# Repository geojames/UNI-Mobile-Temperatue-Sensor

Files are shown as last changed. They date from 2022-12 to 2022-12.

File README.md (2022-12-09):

# UNI-Mobile-Temperatue-Sensor
Open-source Mobile Air and Surface Temperature Sensor for Urban Heat Island Mapping

### Main Parts List
#### Data Logger
| Qty | Part | Link |
| --- | --- | --- |
| 1 | Adafruit QTPy RP2040 | https://www.adafruit.com/product/4900 | 	
| 1 | Adafruit Miniboost | https://www.adafruit.com/product/4654 |
| 1 | Monochrome 128x64 OLED | https://www.adafruit.com/product/938 |
| 1 | 3-AA Battery Holder | https://www.adafruit.com/product/4779 |
| 1 | SparkFun OpenLog | https://www.sparkfun.com/products/13712 |
| 6 | Stemma Cables 50mm | https://www.adafruit.com/product/4399 |
| 1 | SPDT Toggle Switch | https://www.adafruit.com/product/3221 |
| 1 | Main Circuit Board (in CircuitBoard folder) | |
#### Sensors
| Qty | Part | Link |
| --- | --- | --- |
| 1 | Adafruit Mini GPS | https://www.adafruit.com/product/4415 |
| 1 | Melexis MLX90614 | https://www.adafruit.com/product/1747 |
| 1 | Adafruit SHT40 (Temp) | https://www.adafruit.com/product/4885 |
| 1 | Adafruit BH1750 (Light) |  https://www.adafruit.com/product/4681 |
| 1 | Stemma QT JST SH Conn | https://www.adafruit.com/product/4208 |
| 1 | MLX Circuit Board (in CircuitBoard folder) | |
#### Accessories
| Qty | Part | Link |
| --- | --- | --- |
| 1 | MicroSD card (8gb)
| 1 | 36" (1m) USB Cable | https://www.adafruit.com/product/592 | 
|  | or 4con x 28AGW Cable | https://www.digikey.com/en/products/detail/cnc-tech/2725-2828-BL-01000-T/6023699 |
| 1 | JST PH 2-Pin Cable 100mm | https://www.adafruit.com/product/261 |
| 2 | JST PH 2-pin Board Conn | https://www.digikey.com/en/products/detail/jst-sales-america-inc/B2B-PH-K-S-LF-SN/926611 |
| 1 | Suction cup lifter | https://www.harborfreight.com/automotive/auto-body-trim/windows-windshields/suction-cup-lifters/4-23-in-125-lb-dual-suction-cup-lifter-57501.html |
|(optional)| | |
| 1 | JST PH 4-pin Cable  | https://www.adafruit.com/product/3955 |
| 1 | JST PH 4-pin Bard Connector | https://www.digikey.com/en/products/detail/jst-sales-america-inc/B4B-PH-K-S-LF-SN/926613 |
#### Hardware
| Qty | Part | Link |
| --- | --- | --- |
| 1 | M2.5 Standoff Kit | https://www.adafruit.com/product/3658 |
| 10 | M2.5 Heatset inserts | https://www.mcmaster.com/94459A439 |
| 10 | M3 Heatset inserts | https://www.mcmaster.com/94459A130 |
| 4 | M4 Heatset inserts | https://www.mcmaster.com/94459A160 |
| 4 | M3 x 60mm Panhead Screw | https://www.mcmaster.com/catalog/92005A140 |
| 4 | M3 x 10mm Hexdrive Screw | https://www.mcmaster.com/catalog/92095A182 |
| 4 | M4 x 12mm Button head | https://www.mcmaster.com/catalog/92137A307 |
| 2 | M4 x 30mm Hexhead Screw | https://www.mcmaster.com/catalog/91287A118 |
| 2 | M4 Wingnut | https://www.mcmaster.com/catalog/94300A310 |
| 2 | M4 Flat washer | https://www.mcmaster.com/catalog/98688A114 |
| 2 | M4 Internal-Tooth Washer | https://www.mcmaster.com/93925A419 |
| 2 | Rubber washer (~0.3" ID x 1" OD) | https://www.mcmaster.com/90133A260/ |

#### Tools 
Soldering Iron, Solder, Wire strippers, Diagonal cutters, Screw drivers, Allen keys

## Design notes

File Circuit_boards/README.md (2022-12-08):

# UNI-Mobile-Temperatue-Sensor
## Circuit Board Files

These file contain the GERBER files nessesary to order the circuit boards for this project.

The basic configuation for a 2-sided circuit board from any of the major online vendors will be fine.

I use https://jlcpcb.com/

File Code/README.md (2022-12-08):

# UNI-Mobile-Temperatue-Sensor
## Circuit Python Firmware, Code, Libraries

### Firmware
Upload the firmware *.uf2 file to QTPY RP2040
- https://learn.adafruit.com/adafruit-qt-py-2040/circuitpython

### Code and Libraries
Copy the 'lib' folder and the code.py file to the mounted CircuitPython drive

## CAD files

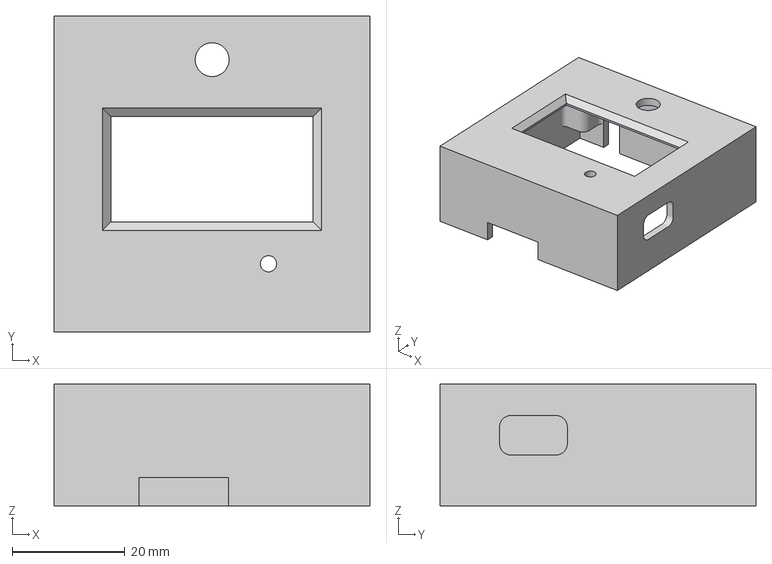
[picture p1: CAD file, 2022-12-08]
3D_Prints/data_MainBody.3mf
56.0 x 56.0 x 21.6 mm

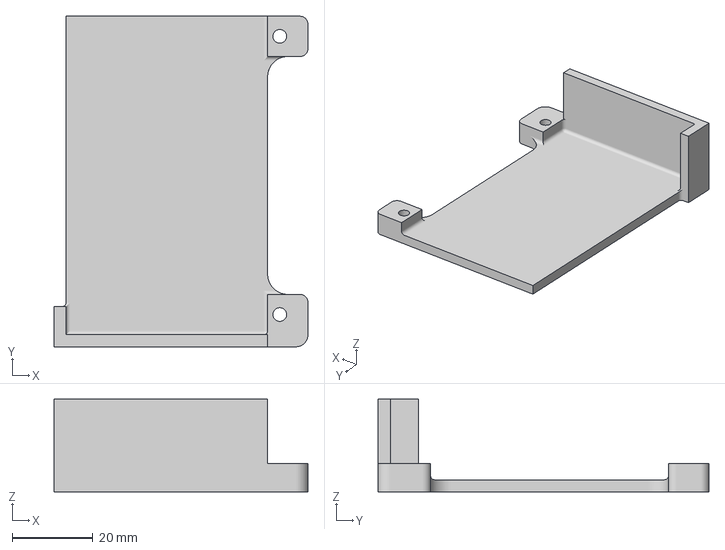
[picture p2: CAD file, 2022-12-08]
3D_Prints/data_Batt_plate.3mf
63.0 x 82.0 x 23.0 mm

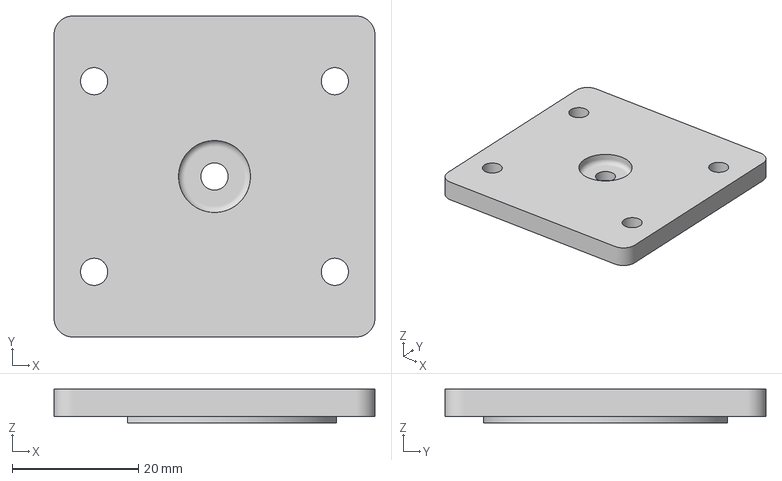
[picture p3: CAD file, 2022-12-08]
3D_Prints/elbow_plate_v3.3mf
50.8 x 50.8 x 5.38 mm

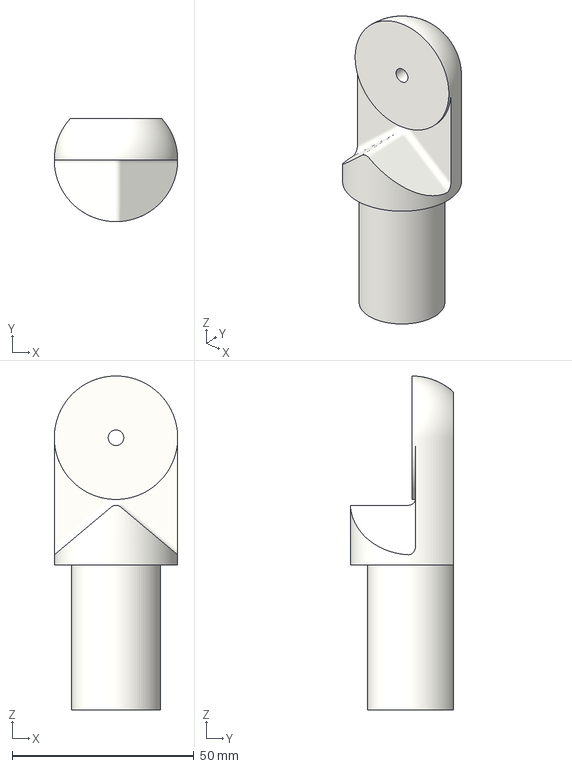
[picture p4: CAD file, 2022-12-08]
3D_Prints/elbow_bottom_v3.3mf
34.0 x 28.5 x 92.0 mm

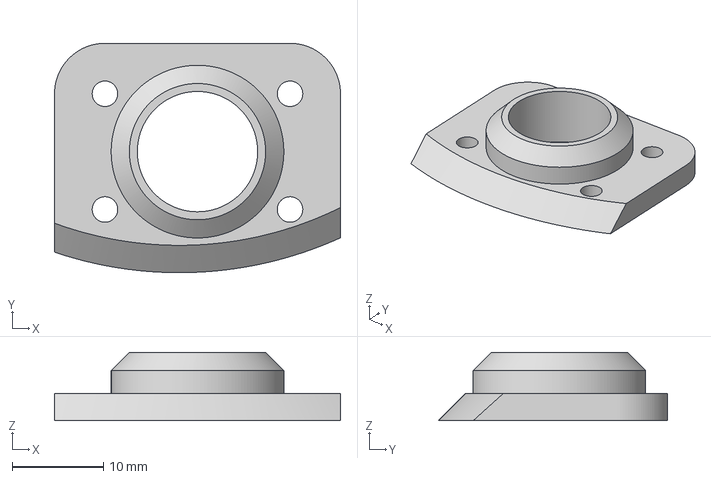
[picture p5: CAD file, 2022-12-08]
3D_Prints/Light_cap_v2.3mf
31.4 x 25.2 x 7.50 mm

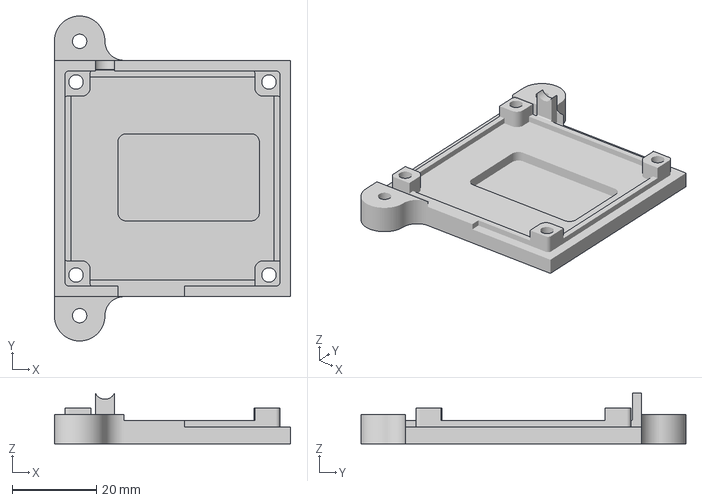
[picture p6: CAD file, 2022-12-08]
3D_Prints/data_BackLid.3mf
56.0 x 77.0 x 12.0 mm

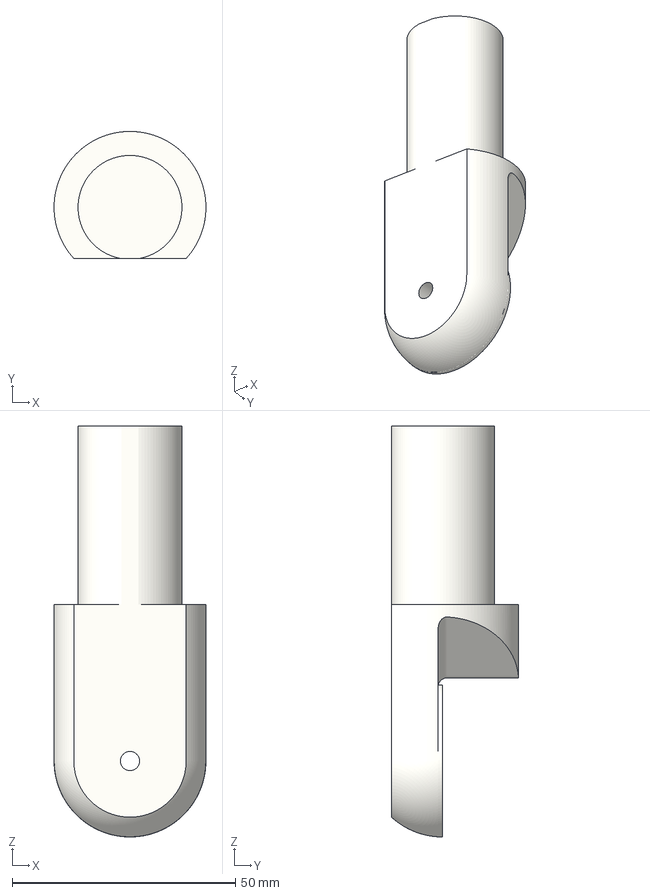
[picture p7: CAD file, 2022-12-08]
3D_Prints/elbow_middle_v3.3mf
34.0 x 28.5 x 92.0 mm

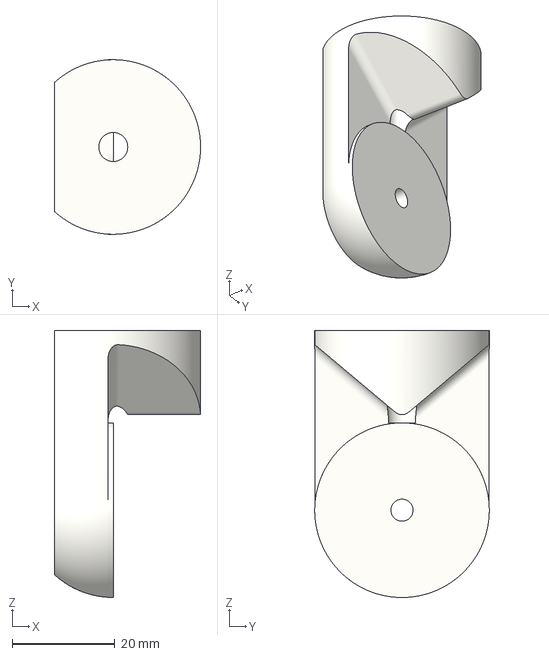
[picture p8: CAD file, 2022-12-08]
3D_Prints/elbow_top_v3.3mf
28.5 x 34.0 x 52.0 mm

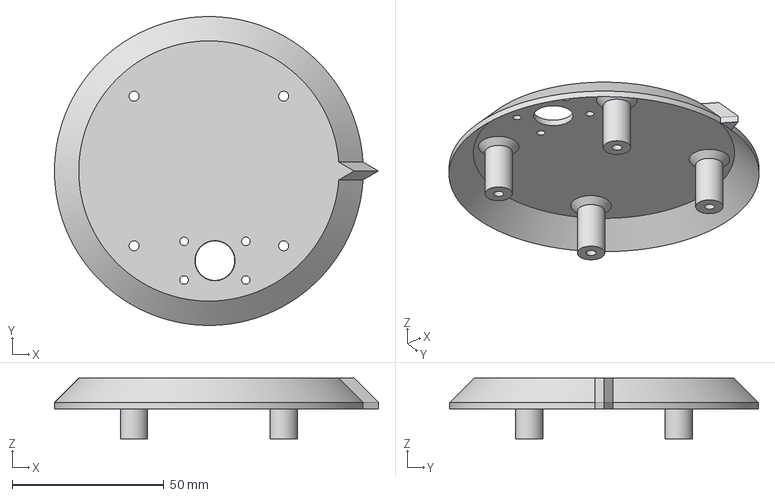
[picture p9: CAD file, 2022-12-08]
3D_Prints/Top_Light_v2.3mf
106.6 x 101.6 x 20.0 mm

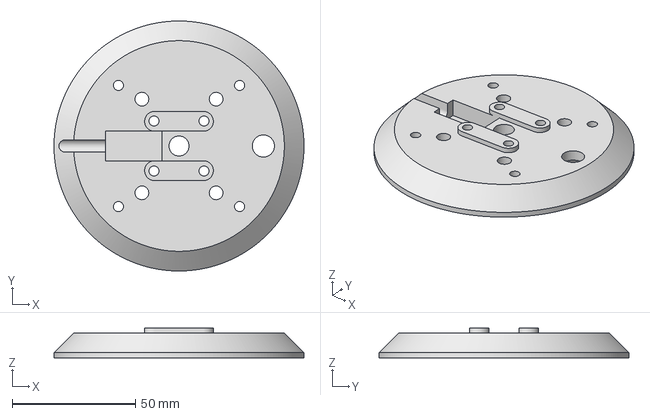
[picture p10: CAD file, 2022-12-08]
3D_Prints/Base_AMPS_v2.3mf
101.6 x 101.6 x 12.2 mm

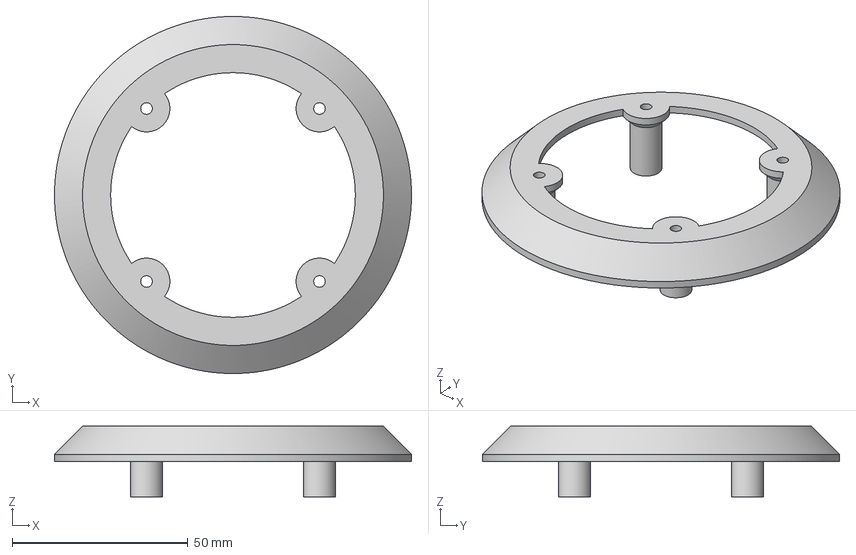
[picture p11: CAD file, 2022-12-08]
3D_Prints/Mid_Louver_v2.3mf
101.6 x 101.6 x 20.1 mm

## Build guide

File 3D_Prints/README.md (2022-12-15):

# UNI-Mobile-Temperatue-Sensor
## 3D Print Files

Print one of each file, execpt Elbow_middle - print two.

I printed in white PLA with 3 perimiters and 15% infill. Most of the models have a large flat surface from printing (most rotated to print "upsidedown"). No supports should be needed.

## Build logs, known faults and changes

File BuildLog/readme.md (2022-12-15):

# Basic build log for the sensors

### More detailed build log coming in early 2024

1. Print 3D Parts add heat set inserts per the images below
2. Order Circuit Boards - assemble per the photos below
3. Suction mount - Cut the suction mount in half across the handle, drill and add heat set inserts
4. Arm - Epoxy the arm/elbow parts into the suction mount and aluminium pipe
5. Assemble all the parts together
6. Upload the Circuit Python Firmware (Code folder) to the QTPy RP2040
7. Uploard the main logging code to the QTPy
---
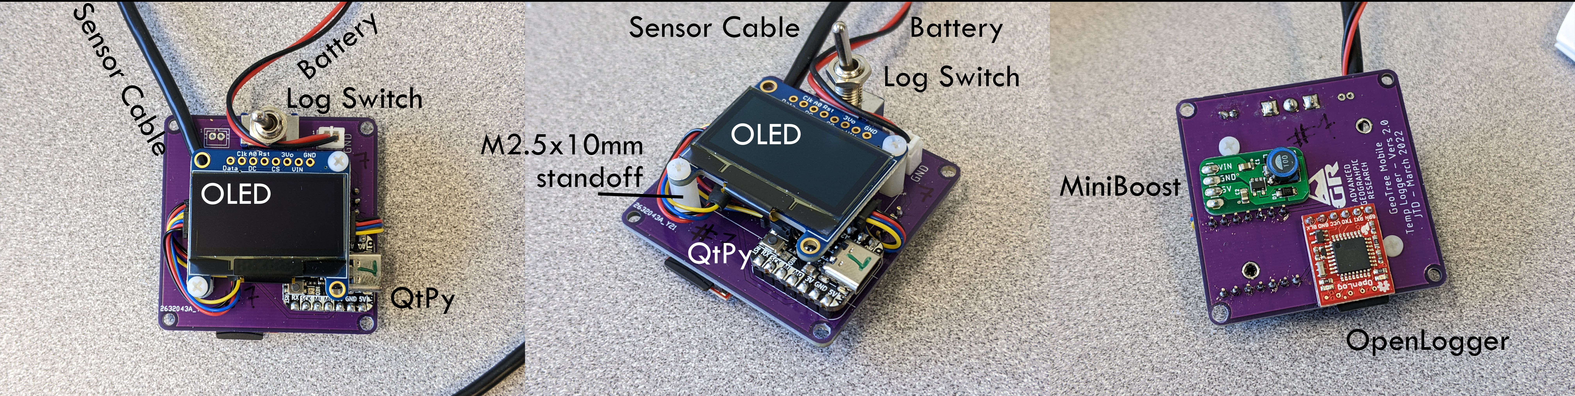
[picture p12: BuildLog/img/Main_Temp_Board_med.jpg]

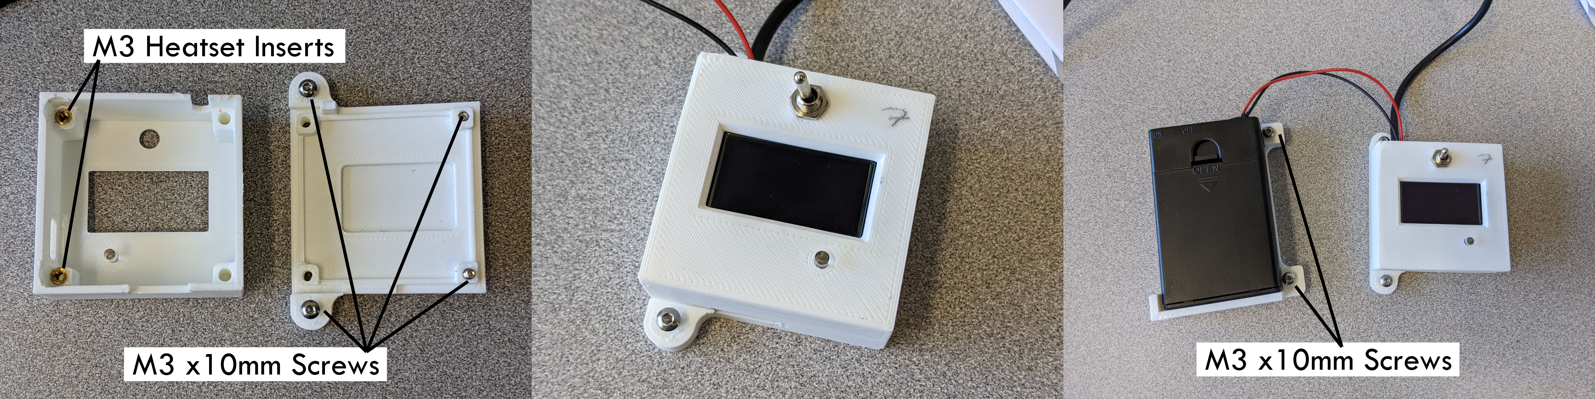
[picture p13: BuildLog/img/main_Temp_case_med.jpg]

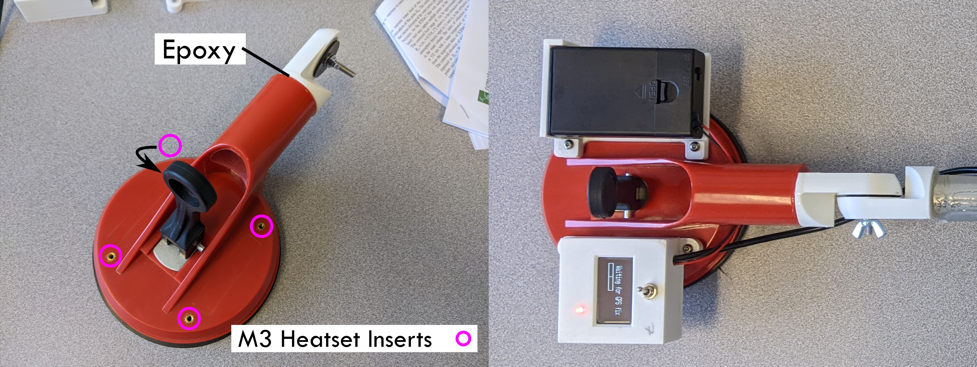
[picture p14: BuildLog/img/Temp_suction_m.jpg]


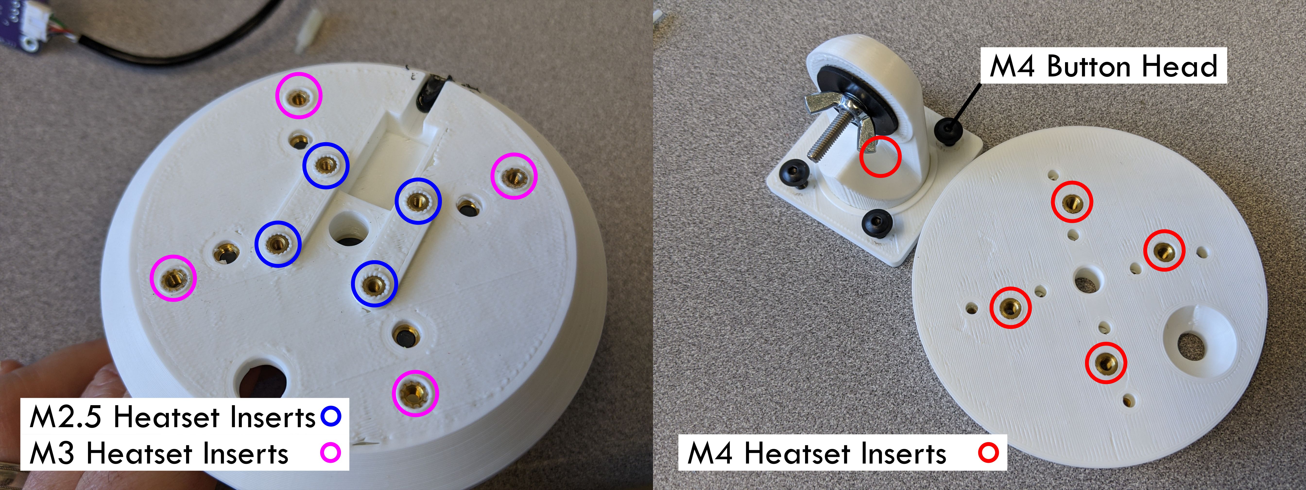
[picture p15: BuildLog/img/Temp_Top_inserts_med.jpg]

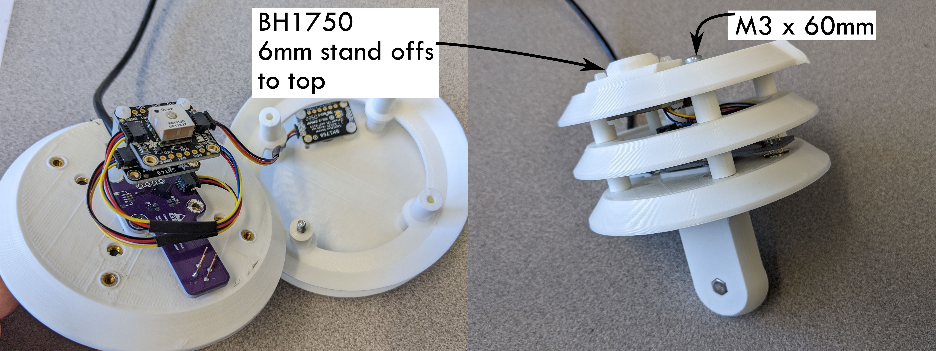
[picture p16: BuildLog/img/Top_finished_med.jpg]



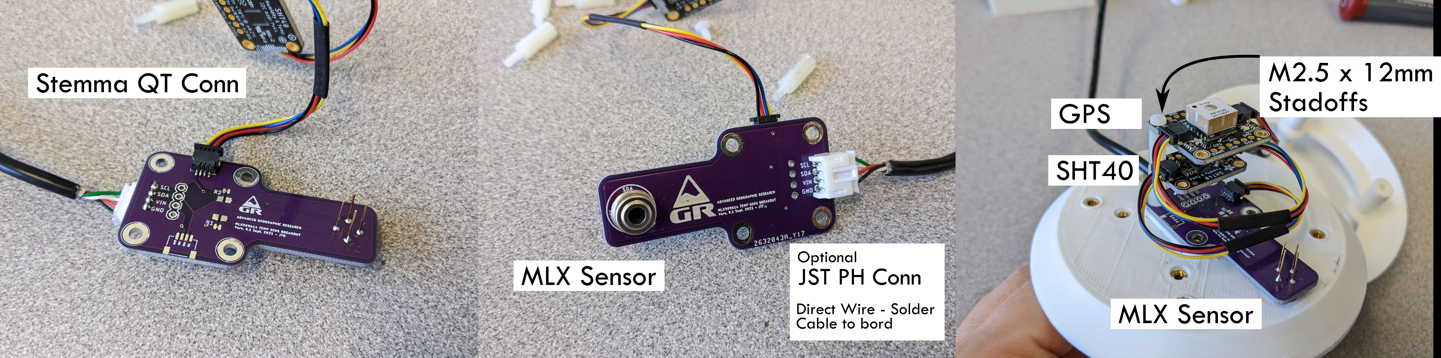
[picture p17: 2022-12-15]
BuildLog/img/Top_MLX_stack_med.jpg

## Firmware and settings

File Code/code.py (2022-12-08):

# -*- coding: utf-8 -*-
# VERSION  5.4, July 2022
# FOR Circuit Pyhton vers. 6.3 (2021-06-01)

import time
import board
import busio
import displayio
import digitalio
import adafruit_ssd1306
import adafruit_sht4x
import adafruit_mlx90614
import adafruit_bh1750
import adafruit_gps
import neopixel

run = True
i2c = busio.I2C(board.SCL1, board.SDA1)
uart = busio.UART(board.TX, board.RX, baudrate=9600)

pixel = neopixel.NeoPixel(board.NEOPIXEL, 1)
pixel.fill((255, 0, 0))
log_switch = digitalio.DigitalInOut(board.D1)
log_switch.direction = digitalio.Direction.INPUT
log_switch.pull = digitalio.Pull.DOWN
oled_reset = digitalio.DigitalInOut(board.D0)
display = adafruit_ssd1306.SSD1306_I2C(128, 32, i2c, addr=0x3D, reset=oled_reset)
display.fill(1)
display.show()
WIDTH = 128
HEIGHT = 64
text = "GEOTREE TEMP LOGGER\nVers. 0.54 + July21"
display.fill(0)
display.text(text, 7, 7, 1)
display.show()
try:
    sht = adafruit_sht4x.SHT4x(i2c)
    sht.mode = adafruit_sht4x.Mode.NOHEAT_HIGHPRECISION
except:
    text = "ERROR:\nTemp Sensor Not Found"
    display.fill(0)
    display.text(text, 7, 0, 1)
    display.show()
try:
    mlx = adafruit_mlx90614.MLX90614(i2c)
except:
    text = "ERROR:\nSurface Not Found"
    display.fill(0)
    display.text(text, 7, 0, 1)
    display.show()
try:
    lux = adafruit_bh1750.BH1750(i2c)
except:
    text = "ERROR:\nLight Not Found"
    display.fill(0)
    display.text(text, 7, 0, 1)
    display.show()
try:
    gps = adafruit_gps.GPS_GtopI2C(i2c)
    gps.send_command(b"PMTK314,0,1,0,0,0,0,0,0,0,0,0,0,0,0,0,0,0,0,0")
    gps.send_command(b"PMTK220,500")
    gps.update()
except:
    text = "ERROR:\nGPS Not Found"
    display.fill(0)
    display.text(text, 7, 0, 1)
    display.show()

last_print = time.monotonic()
while log_switch.value is True:
    text = "!!!!!!\nTurn Log Swictch\nto OFF to continue\n!!!!!!"
    display.fill(0)
    display.text(text, 7, 0, 1)
    display.show()
    pixel.fill((255, 0, 0))
    time.sleep(0.5)
fix_count = 0
while gps.has_fix is False:
    text = "Waiting for GPS fix"
    gps.update()
    current = time.monotonic()
    if current - last_print >= 1:
        last_print = current
        if fix_count == 0:
            display.fill(0)
            display.text(text, 7, 8, 1)
            display.rect(0, 18, int(WIDTH * 0.25), 6, 1)
            display.show()
            pixel.fill((255, 0, 0))
        elif fix_count == 1:
            display.rect(0, 18, int(WIDTH * 0.5), 6, 1)
            display.show()
            pixel.fill((50, 0, 0))
        elif fix_count == 3:
            display.rect(0, 18, int(WIDTH * 0.75), 6, 1)
            display.show()
            pixel.fill((255, 0, 0))
        elif fix_count == 4:
            display.rect(0, 18, int(WIDTH), 6, 1)
            display.show()
            pixel.fill((50, 0, 0))
        fix_count += 1
        if fix_count >= 5:
            fix_count = 0
file_num = 1
ready_sw = 0
print("GPS WAITING: %i" % gps.in_waiting)

while gps.in_waiting > 24:
    data = gps.read(200)
    print("flush...")
while run == True:
    if log_switch.value is False:
        if ready_sw == 0:
            gps.update()
            log_state = 0
            pixel.fill((0, 255, 0))
            display.fill(0)
            text = "GPS READY...\n  Toggle Switch\n  to Start Logging"
            display.text(text, 7, 2, 1)
            display.show()
            time.sleep(1.0)
            ready_sw = 1
    elif log_switch.value is True:
        gps.update()
        current = time.monotonic()
        # print("*** Time *** %0.3f"%(current - last_print))
        if log_state == 0:
            log_state = 1
            ready_sw = 0
            ready_sw = 0
            fname = "%02d%02d%02d%02d.TXT" % (
                int(str(gps.timestamp_utc.tm_year)[-2:]),
                gps.timestamp_utc.tm_mon,
                gps.timestamp_utc.tm_mday,
                file_num,
            )
            uart.write(bytearray("###\r"))
            time.sleep(0.5)
            uart.write(bytearray("ls\r"))
            f_list = uart.read(2000)
            print(f_list)
            if f_list is None:
                display.fill(0)
                text = "NO SD CARD DETECTED\n-Insert card and\n restart unit"
                pixel.fill((255, 0, 0))
                display.text(text, 7, 2, 1)
                display.show()
                run = False
                break

            else:
                while fname in str(f_list):
                    print("Next: %s" % fname)
                    file_num += 1
                    fname = "%02d%02d%02d%02d.TXT" % (
                        int(str(gps.timestamp_utc.tm_year)[-2:]),
                        gps.timestamp_utc.tm_mon,
                        gps.timestamp_utc.tm_mday,
                        file_num,
                    )
                uart.write(bytearray("append " + fname + "\r"))
                time.sleep(0.5)
                print(fname)
                pixel.fill((0, 0, 255))
                display.fill(0)
                text = "Output File = \n \n  " + fname
                display.text(text, 7, 2, 1)
                display.show()
                time.sleep(5.0)
                log_start_time = time.monotonic()
                file_num += 1
                #gps.update()

        data = gps._read_sentence()
        print(data)  # this is a bytearray type
        if data is not None:
            # convert bytearray to string
            # data_string = "".join([chr(b) for b in data])
            # print(data_string, end="")

            uart.write(bytearray(data + "\n"))
            time.sleep(0.1)

            #print('TIME:'+data[7:9]+':'+data[9:11]+':'+data[11:13])
            temp, rel_hum = sht.measurements
            mlx_atemp = mlx.ambient_temperature
            mlx_otemp = mlx.object_temperature
            light = lux.lux
            sens_data = ">,%0.2f,%0.2f,%0.2f,%0.2f,%0.2f\n" % (
                temp,
                rel_hum,
                mlx_atemp,
                mlx_otemp,
					light
            )
            uart.write(bytearray(sens_data))
            time.sleep(0.1)
            print("write...")
            display.fill(0)
            log_cur_time = time.monotonic() - log_start_time
            #print(log_cur_time)
            log_cur_lbl = "Logging Time + %02d:%02d\n" % (
                log_cur_time // 60,
                log_cur_time - (log_cur_time // 60) * 60,
            )
            text = log_cur_lbl + "Temp: %0.1f C\nHum:  %0.1f %%\nSurf: %0.1f C  L:%i" % (
                temp,
                rel_hum,
                mlx_otemp,
					light
            )
            display.text(text, 0, 0, 1)
            display.show()
